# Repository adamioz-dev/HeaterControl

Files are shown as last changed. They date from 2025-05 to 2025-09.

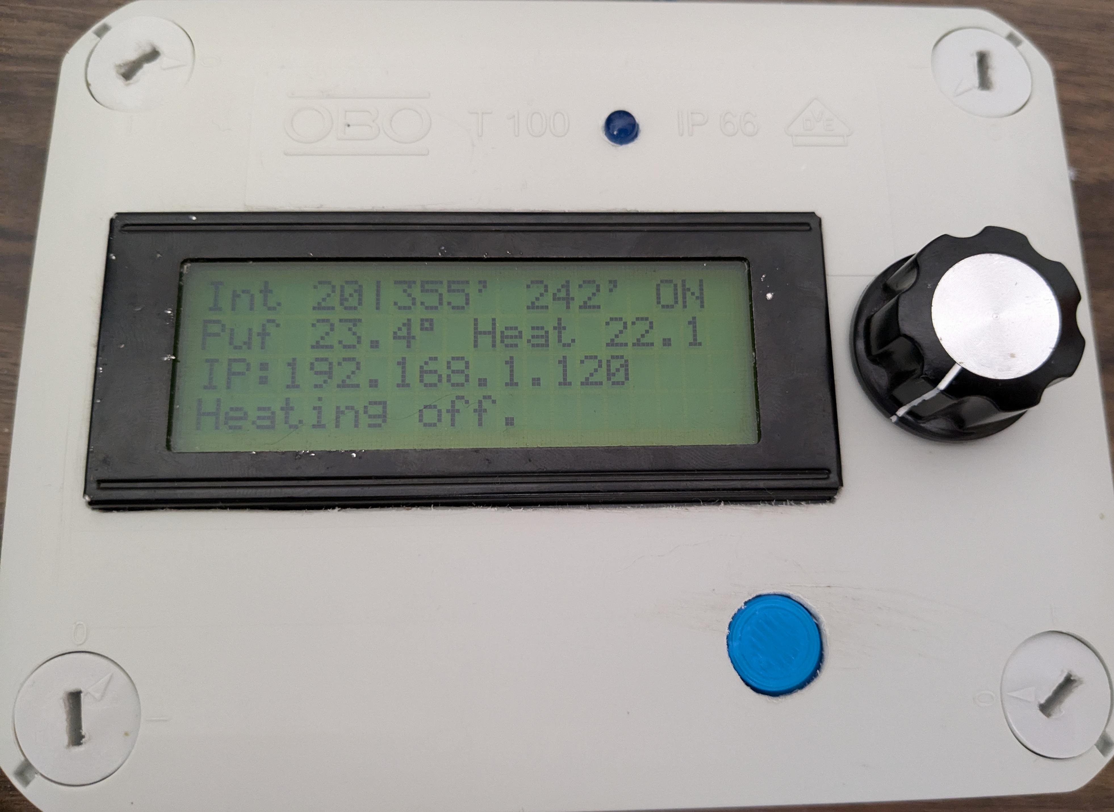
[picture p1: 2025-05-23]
resources/Assembly_front_in_electrical_box.jpg

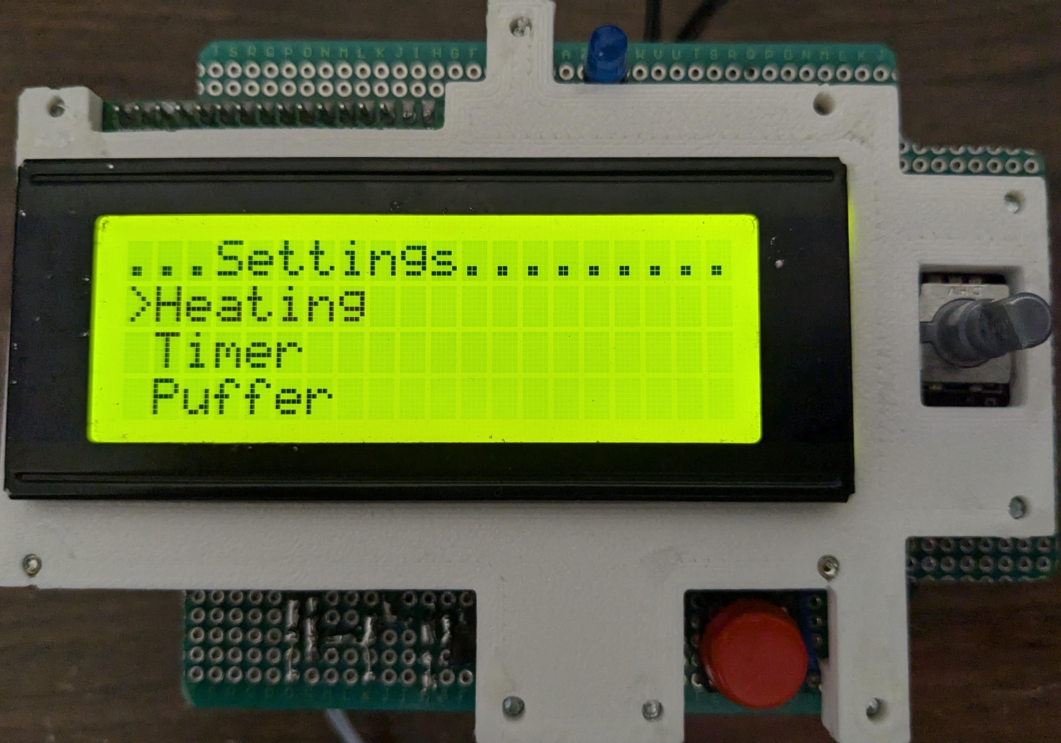
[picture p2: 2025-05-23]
resources/Assembly_front.jpg

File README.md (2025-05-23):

# HeaterControl
The repository contains the code for a heater control project based on the Arduino framework using the PlatformIO envirmoment using python scripts to perform automatic versioning. 

About the project: 
This is used for fire wood heaters which come with water rezervoirs (puffer) to store the heat generated and distribuite it when needed.
The hot water from the rezervoir is transfered to the building heater system to heat it up, this is achieved by controling the pump with a relay. 

Features as implemented in each controller:
1) The slave atmega328 controller (arduino uno) responsable for:
- inputs (lcd, encoder, button, (optional) external termostat on/off connection)
- relay control (for controlling the water pump to transfer heat from the puffer to the building)
- temperature measurements (heater water temperature and the puffer temperature - min/max can be set)
- over-temperature protection for the puffer.
- prevent enabling of pump when the puffer temperature is too low and heating is not possible.
- communicate the measurement/settings/states to the master controller on UART.
2) The master esp8266 controller (nodemcu)  responsable for:
- handle conection to the internet using WiFi
- hosting web pages for settings, control, data logging available on local network.
- conection with blynk (for smartphone access anywhere, blynk OTA) (optional)
- flashing over the air (OTA on same network)
- flashing of slave controller when update is received.
- receive room temperature measurements over direct HTTP or MQTT connection (MQTT broker required).
- MQTT publish measurements and subscribe to control values and room temperature (MQTT broker required).
- estimate home room temperature if it was not received for some time (for up to 2h)

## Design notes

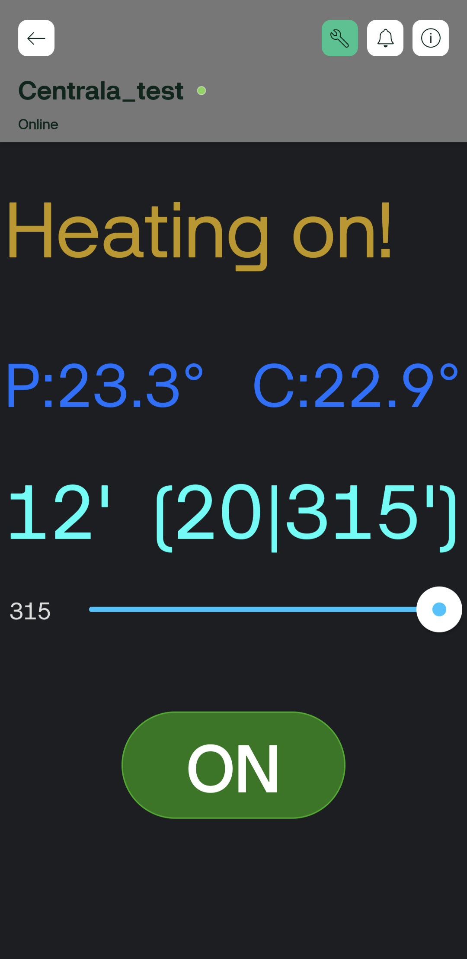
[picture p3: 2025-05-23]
resources/blynk_app_example.png

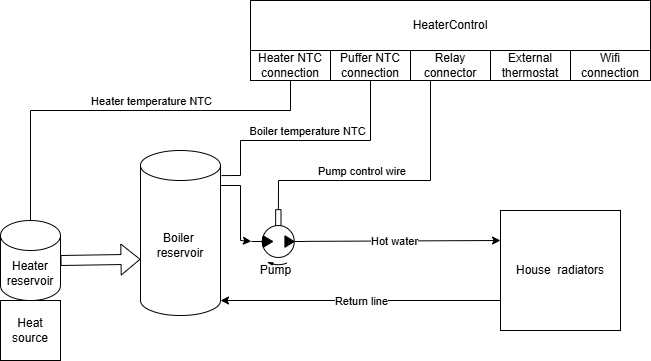
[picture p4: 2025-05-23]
resources/InstalationDiagram.png

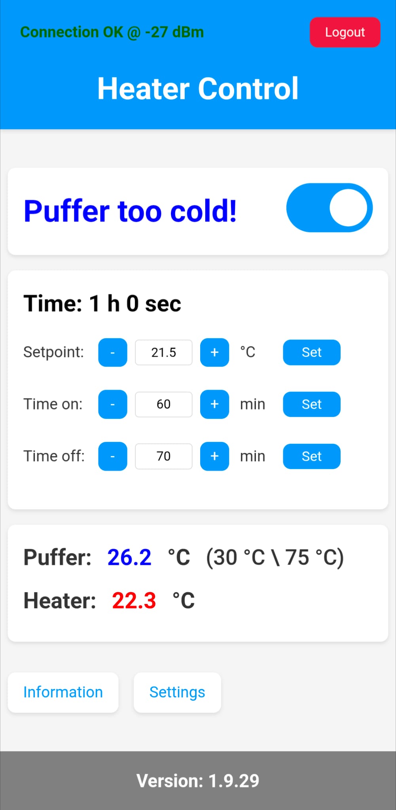
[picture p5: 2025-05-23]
resources/WebPage.jpg

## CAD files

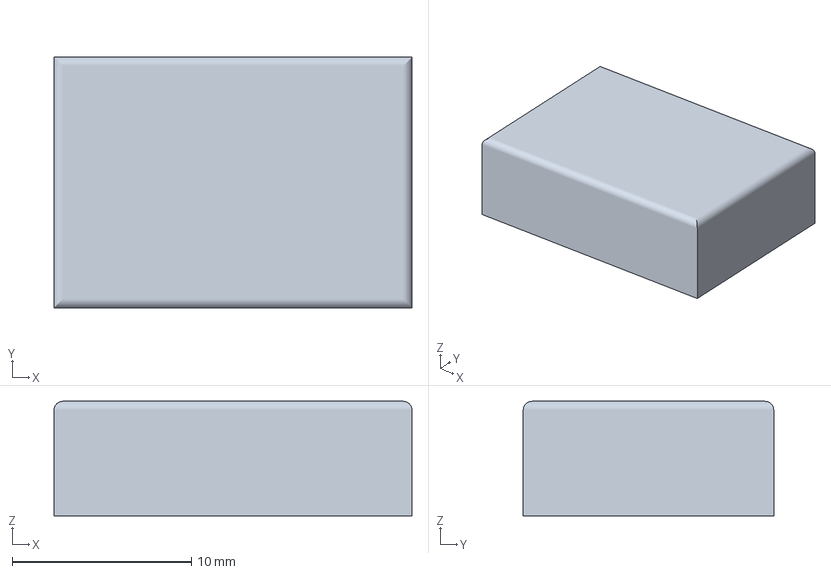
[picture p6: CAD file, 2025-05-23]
resources/3d_models/encoder_stand.3MF
20.0 x 14.0 x 6.40 mm

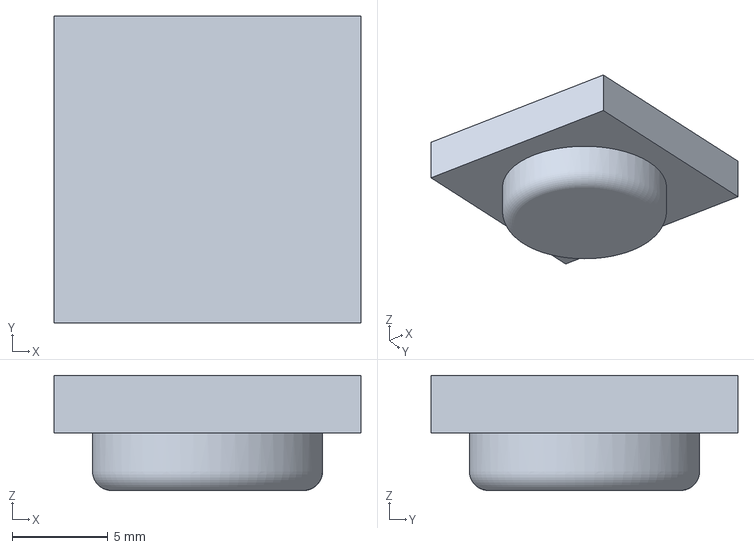
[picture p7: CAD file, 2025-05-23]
resources/3d_models/button_riser.3MF
16.0 x 16.0 x 6.00 mm

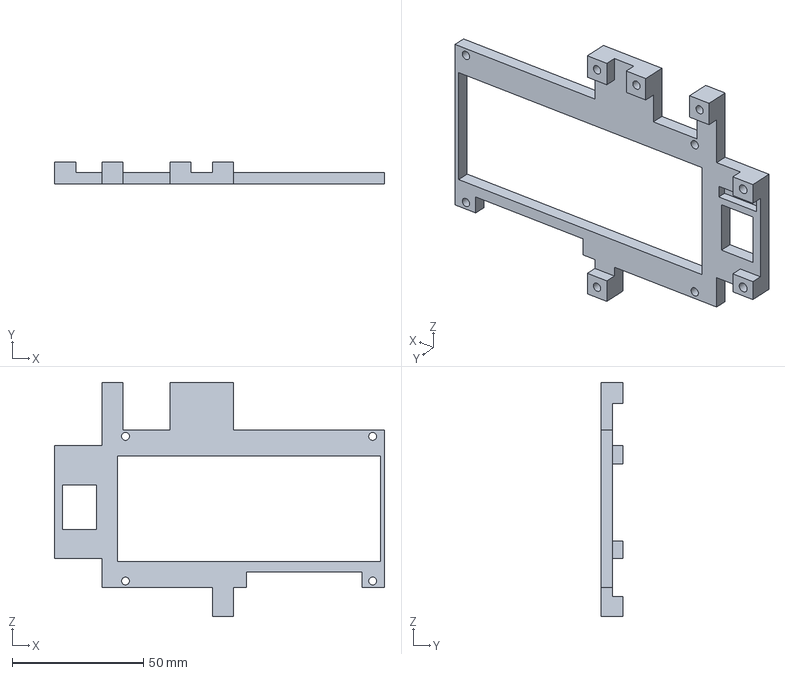
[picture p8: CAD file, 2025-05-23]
resources/3d_models/PCB_holder_frame.3MF
125.5 x 8.50 x 89.0 mm

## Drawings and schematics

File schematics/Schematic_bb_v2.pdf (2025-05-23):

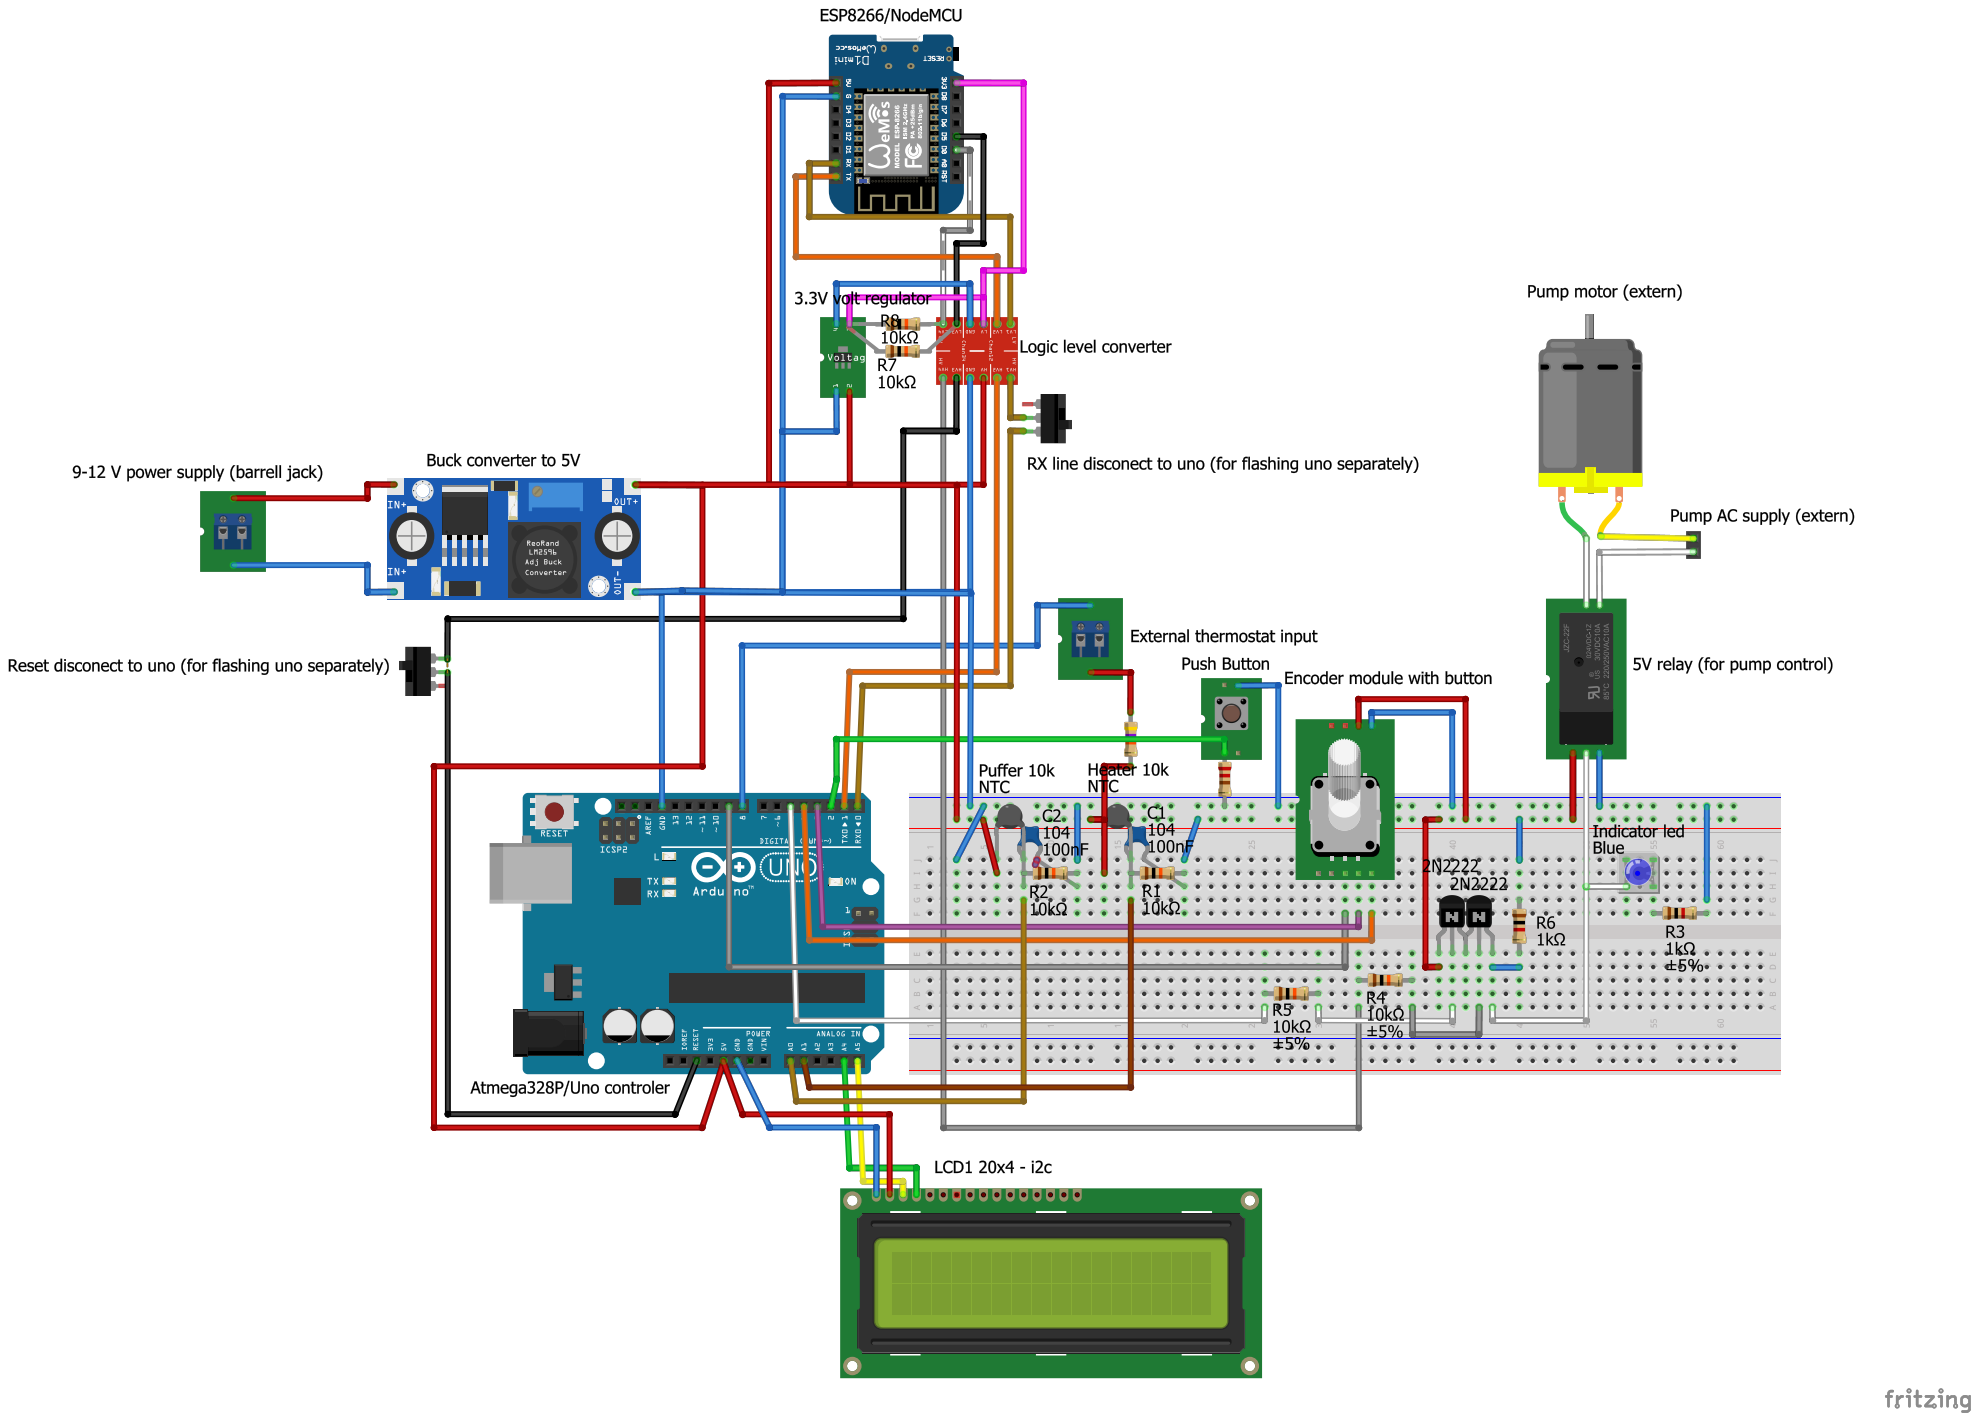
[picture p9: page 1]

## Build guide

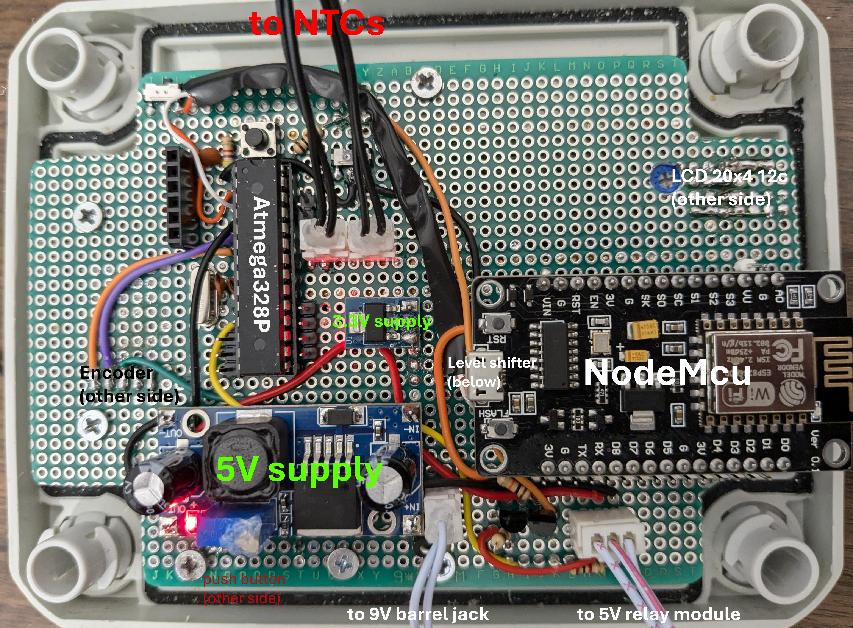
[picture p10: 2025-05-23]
resources/Assembly_back.jpg

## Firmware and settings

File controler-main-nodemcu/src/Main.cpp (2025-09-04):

// *********************************************************************
// INCLUDES
// *********************************************************************
#include "Main.h"
#include <EEPROM.h>
#include "ProjVersion.h"
#include "MQTT.h"
// *********************************************************************
// DEFINES
// *********************************************************************

// *********************************************************************
// DATATYPES
// *********************************************************************
struct {
  uint32_t flash_request;
  uint32_t flash_attempts;
  uint32_t reserved[3];
} rtcData;

typedef struct {
  // heating parameters
  float heating_puffer_coef =       200;
  float heating_result_multiplier = 2;
  // cooling params
  float cooling_room_coef =         75;
  float cooling_result_multiplier = 12;
}tempAproxCalib_t;

// *********************************************************************
// GLOBAL VARIABLES
// *********************************************************************
// temp aproximation calib data
tempAproxCalib_t calibData;

//room temperature timeout counter
uint16_t roomTempUpdateTimeout_cnt = 0u;

// intervals for scheduler
unsigned long g_fast_task_interval_cnt =    0; 
unsigned long g_mid_task_interval_cnt =     0; 
unsigned long g_slow_task_interval_cnt =    0; 
unsigned long g_minute_task_interval_cnt =  0; 

// comunicated values 
ComTransmitData comTransmitData;

// uptime counter
unsigned long g_esp_uptime = 0; 

// data received marker
bool data_received = false;

// marker for communication error, starup flag set as error present
bool communication_error = true;

//webserver request flags 
bool uno_flash_req_flag = false;
bool uno_reset_req_flag = false;
bool esp_reset_req_flag = false;

/* Init value */
flash_resp_t flash_status = FLASH_INFO_NOT_AVAIL;

/* extern stuff */
extern bool AP_mode_active; 

// *********************************************************************
// FUNCTION DECLARATIONS 
// *********************************************************************
void versionCheck();
void mqttCallback(char* topic, byte* payload, unsigned int length);

// *********************************************************************
// FUNCTIONS
// *********************************************************************

void reset_uno(){
  // reset the uno controler
  DEBUG_PRINT_LN("Reset the AVR UNO");
  digitalWrite(UNO_RESET_PIN, LOW); // when pulled low, the uno will reset
  delay(100);
  digitalWrite(UNO_RESET_PIN, HIGH); // return to normal
  delay(50);
}

void check_uno(){
  // must be called slower than the uni will report the time
  uint32_t local_uno_uptime = comTransmitData.get_unoUptime();
  static uint32_t local_uno_uptime_prev = 0;
  static uint8_t local_reset_timeou_cnt = 0;

  static uint8_t local_reset_attepmts_cnt = 0;
  // uptime did not change
  if (local_uno_uptime_prev == local_uno_uptime)
  {
    // reset after the sepecified periods (in 10s of seconds)
    if ((local_reset_timeou_cnt >= UNO_RESET_WAIT) && (local_reset_attepmts_cnt <= UNO_RESET_TRIES))
    {
      // timeout of communication with uno, watchdog of uno failed to reset, communication not restored
      DEBUG_PRINT_LN("Resetting uno!");
      reset_uno();
      // clear reset counter
      local_reset_timeou_cnt = 0;
      // increment reset attempts
      local_reset_attepmts_cnt += 1;      
    }
    else if (local_reset_attepmts_cnt > UNO_RESET_TRIES)
    {
      DEBUG_PRINT_LN("Resettings failed, flash uno!");
      // attempt flashing
      flash_uno_req();
      // clear max reset counter, uno will be re-flashed 
      local_reset_attepmts_cnt = 0;
    }
    else
    {
      /* counter not finished yet */
      // uno is not sending data, increase reset counter
      local_reset_timeou_cnt++;
    }

    /* update reported state with error message */
    communication_error = true;
    /* set com error */
    (void)comTransmitData.set_Feedback((uint8_t)UNO_COM_ERR);
  }
  else
  {
    // connection seems ok, clear reset counter as well
    local_reset_attepmts_cnt = 0;
    // comunication restored, clear counter
    local_reset_timeou_cnt = 0;
    /* update reported state with error message */
    communication_error = false;
    /* Com error wil be cleared with the new feedback received */
  }

  // save previous uptime
  local_uno_uptime_prev = local_uno_uptime;
}

String processFeedbackCode(){
  uint8_t local_feedback_code = comTransmitData.get_Feedback();
  String returnText = "";
  /* normal operation */
  switch(local_feedback_code)
  {
    case HEATING_OFF: 
      {
      returnText = F("Heating off."); //heat off
      }
      break;
    case HEATING_ON:
      {
      returnText = F("Heating on!"); //heat on
      }
      break;
    case PUFFER_TEMP_LOW:
      {
      returnText = F("Puffer too cold!"); //low temp
      }
      break;
    case PUFFER_TEMP_OVERHEAT:
      {
      returnText = F("Puffer too hot!"); //high temp
      }
      break;
    case UNO_COM_ERR:
      {
      returnText = F("Control error!"); // uno not responding
      }
      break;
    default:
      {
      returnText = F("Unknown!");
      }
      break;  
  }
  
  return returnText;
}

void receiveValue(uint8_t id, uint32_t value){
  // set the value of the received variable
  //DEBUG_PRINT("Received:");
  //DEBUG_PRINT(id);
  //DEBUG_PRINT("=");
  //DEBUG_PRINT_LN(value);
  switch (id)
  {
    case _ID_HEATER_MODE:
    {
      //DEBUG_PRINT("UNO: Mode request ");
      //DEBUG_PRINT_LN(value);
      (void)comTransmitData.setHeating_mode((uint8_t)value);
      break;
    }
    case _ID_TIMER_ON_TIME:
    {
      //DEBUG_PRINT("UNO: Timer on ");
      //DEBUG_PRINT_LN(value);
      (void)comTransmitData.setHeatingTimer_ontime((uint16_t)value);
      break;
    }
    case _ID_TIMER_OFF_TIME:
    {
      //DEBUG_PRINT("UNO: Timer off ");
      //DEBUG_PRINT_LN(value);
      (void)comTransmitData.setHeatingTimer_offtime((uint16_t)value);
      break;
    }
    case _ID_AMBIENT_TARGET_TEMP:
    {
      //DEBUG_PRINT("Target room temp update from UNO: ");
      //DEBUG_PRINT_LN(value);
      (void)comTransmitData.setHeatingTermostat_target_ambient((uint16_t)value);
      break;
    }
    case _ID_AMBIENT_HYSTERESIS:
    {
      (void)comTransmitData.setHeatingTermostat_hysteresis((uint8_t)value);
      break;
    }
    case _ID_PUFFER_MIN_TEMP:
    {
      (void)comTransmitData.setPuffer_minTemp((uint8_t)value);
      break;
    }
    case _ID_PUFFER_MAX_TEMP:
    {
      (void)comTransmitData.setPuffer_maxTemp((uint8_t)value);
      break;
    }
    case _ID_PUFFER_HYSTERESIS:
    {
      (void)comTransmitData.setPuffer_hysteresis((uint8_t)value);
      break;
    }
    /// runtime values
    case _ID_HEATER_TRIGGER_REQUEST:
    {
      // here is received, don't set the send flag
      (void)comTransmitData.setHeating_TriggerRequest((uint8_t)value);
      break;
    }
    case _ID_TIMER_REMAINING_SEC:
    {
      // receive only, except in case of uno reset-restore
      (void)comTransmitData.setHeatingTimer_TimeRemaining_sec((uint16_t)value);
      break;
    }
    case _ID_AMBIENT_ACTUAL_ROOM_TEMP:  
    {
      // room temperature
      (void)comTransmitData.setHeatingTermostat_AmbientTemp((uint16_t)value, false);
      break;
    }
    case _ID_AMBIENT_ACTUAL_ROOM_TEMP_VALID:
    {
      // room temp valid received
      (void)comTransmitData.setHeatingTermostat_AmbientTemp_Valid((uint8_t)value, false);
      break;
    }
    case _ID_THERMOSTAT_STATE:
    {
      //DEBUG_PRINT("UNO: External thermostat state ");
      //DEBUG_PRINT_LN(value);
      // termostat external pin state
      (void)comTransmitData.setHeatingExternalTermostat_State((uint8_t)value);
      break;
    }
    case _ID_PUFFER_TEMP:
    {
      // receive only
      (void)comTransmitData.setPuffer_Temp((uint16_t)value);
      break;
    }
    case _ID_HEATER_TEMP:
    {
      // receive only
      (void)comTransmitData.setBoiler_Temp((uint16_t)value);
      break;
    }

    case _ID_FEEDBACK_CODE:
    {
      // receive only
      (void)comTransmitData.set_Feedback((uint8_t)value);
      break;
    }
    case _ID_IP_ADDRESS:
    {
      // send only
      break;
    }
    case _ID_UPTIME_UNO:
    {
      // receive only
      (void)comTransmitData.set_unoUptime((uint32_t)value);
      //DEBUG_PRINT("Uptime received:");
      //DEBUG_PRINT_LN(value);
      break;
    }
    case _ID_DATA_GROUP1:
    {
      // send only
      break;
    }
    case _ID_DATA_GROUP2:
    {
      // send only
      break;
    }
    case _ID_VERSION:
    {
      // Receive uno specific data
      version_data_t version_data_temp_store; // temp variable 
      version_data_t version_data_temp_recv; // temp variable 
      // get to temp variable
      version_data_temp_recv.all = (uint32_t)value;

      // get relevant data only, uno version
      version_data_temp_store.version_byte[1] = version_data_temp_recv.version_byte[1]; // uno version

      version_data_temp_store.version_byte[0] = (uint8_t)PROJECT_MAJOR; // keep original
      version_data_temp_store.version_byte[2] = (uint8_t)PROJECT_ESP;   // keep original
      version_data_temp_store.version_byte[3] = (uint8_t)flash_status;  // keep original
      // store received version
      (void)comTransmitData.set_version_all((uint32_t)version_data_temp_store.all, false);
      break;
    }
    case _ID_LAST:
    {
      // Check if the values are requested and the esp been already running and received data already
      if (((uint8_t)value == 1) && (g_esp_uptime > 60) && (data_received == true)) 
      {
        DEBUG_PRINT_LN("Data was requested. Sending last know data.");
        // data was requested from uno
        // send the confirmation that termostat data is received
        sendPacket(_ID_AMBIENT_ACTUAL_ROOM_TEMP, (uint16_t)(comTransmitData.getHeatingTermostat_AmbientTemp() * FLOAT_SCALING));
        sendPacket(_ID_AMBIENT_ACTUAL_ROOM_TEMP_VALID, (uint8_t)(comTransmitData.getHeatingTermostat_AmbientTemp_Valid()));
        // last known heater request
        sendPacket(_ID_HEATER_TRIGGER_REQUEST, (uint8_t)comTransmitData.getHeating_TriggerRequest()); 
        //timer
        sendPacket(_ID_HEATER_MODE, (uint8_t)comTransmitData.getHeating_mode());
        sendPacket(_ID_TIMER_ON_TIME, (uint16_t)comTransmitData.getHeatingTimer_ontime());
        sendPacket(_ID_TIMER_OFF_TIME, (uint16_t)comTransmitData.getHeatingTimer_offtime());
        sendPacket(_ID_TIMER_REMAINING_SEC, (uint16_t)comTransmitData.getHeatingTimer_TimeRemaining_sec());
        // termostat
        sendPacket(_ID_AMBIENT_TARGET_TEMP, (uint16_t)(comTransmitData.getHeatingTermostat_target_ambient() * FLOAT_SCALING));
        sendPacket(_ID_AMBIENT_HYSTERESIS, (uint8_t)(comTransmitData.getHeatingTermostat_hysteresis() * FLOAT_SCALING));
        // puffer
        sendPacket(_ID_PUFFER_MIN_TEMP,(uint8_t)comTransmitData.getPuffer_minTemp());
        sendPacket(_ID_PUFFER_MAX_TEMP, (uint8_t)comTransmitData.getPuffer_maxTemp());
        sendPacket(_ID_PUFFER_HYSTERESIS, (uint8_t)comTransmitData.getPuffer_hysteresis());
        // send version
        sendPacket(_ID_VERSION, (uint32_t)comTransmitData.get_version_all());
      }
    }
    default:
    {
      break;
    }
  }
  data_received = true;
}

void toogle_led(){
  static bool led_status = false;
  // blink led when alive 
  digitalWrite(LEDPIN, led_status); // turn on led 
  led_status = !led_status;
}

void receiveRoomTemp(float room_temperature)
{
  // float scaling applies for 19.5 send 195
  (void)comTransmitData.setHeatingTermostat_AmbientTemp((uint16_t)(room_temperature * FLOAT_SCALING), true);
  // set valid temp flag
  (void)comTransmitData.setHeatingTermostat_AmbientTemp_Valid((bool)true , true);
  /* reset timeout counter */
  roomTempUpdateTimeout_cnt = 0;
  //call the temp aprox fuction
  aproximateRoomTemp(); 
}

void receiveRoomTempBattery(float battery_volt)
{
  // float scaling applies for 2.8 send 28
  (void)comTransmitData.setHeatingTermostat_AmbientTempBattery((uint8_t)(battery_volt * FLOAT_SCALING));
}

uint16_t calculateTimeToIncreaseTemp(float local_puffer_temp, float local_room_temp)
{
  // calculate time in minutes required to increase temperature by 0.1 C
  uint16_t local_timeStep = (uint16_t)((1 / (local_puffer_temp - local_room_temp) * calibData.heating_puffer_coef) * calibData.heating_result_multiplier);

  DEBUG_PRINT("Calculated time step for increase: "); 
  DEBUG_PRINT_LN(local_timeStep);
  
  return local_timeStep;
}

uint16_t calculateTimeToDecreaseTemp(float local_room_temp)
{
  // calculate time in minutes required to decrease temperature by 0.1 C
  uint16_t local_timeStep =  (uint16_t)((1 / local_room_temp * calibData.cooling_room_coef) * calibData.cooling_result_multiplier);
  
  DEBUG_PRINT("Calculated time step for decrease: "); 
  DEBUG_PRINT_LN(local_timeStep);
  
  return local_timeStep;
}

/* aproximate room temp between measurement points (each min)*/
void aproximateRoomTemp()
{
  static uint16_t local_timeSinceLastTempUpdateByStep = 0;
  static bool local_heating_status_prev = true;
  static uint16_t local_calculatedTempStep = 0u;
  static float local_room_temperature_received = 0;
  static uint8_t local_send_counter = 0;
  static float local_room_temperature_aprox = 0;

  float local_room_temperature = 0;
  uint8_t local_feedback_code = HEATING_OFF;
  bool local_heating_status = false;
  bool local_temperature_data_valid = false;

  float local_puffer_temp = 0;

  local_puffer_temp = comTransmitData.getPuffer_Temp();
  local_room_temperature = comTransmitData.getHeatingTermostat_AmbientTemp();
  local_feedback_code =  (uint8_t)comTransmitData.get_Feedback();
  local_temperature_data_valid = comTransmitData.getHeatingTermostat_AmbientTemp_Valid();

  // check if data is valid
  if((local_temperature_data_valid == false) || (local_room_temperature == 0))
  {
    //DEBUG_PRINT("Room temp not valid -");
    //DEBUG_PRINT_LN(local_temperature_data_valid);
    //DEBUG_PRINT(" T: ");
    //DEBUG_PRINT_LN(local_room_temperature);
    // no valid temp, exit
    local_room_temperature_aprox = 0;
    return;
  }

  // identify what is the heating state
  if ((local_feedback_code == HEATING_OFF) || (local_feedback_code == PUFFER_TEMP_LOW))
  {
    // no heating
    local_heating_status = false;
  }
  else if ((local_feedback_code == HEATING_ON) || (local_feedback_code == PUFFER_TEMP_OVERHEAT))
  {
    // heating is on
    local_heating_status = true;
  }

  // Check if timeout is reached
  if (roomTempUpdateTimeout_cnt >= ROOM_TEMP_TIMEOUT)
  {
    DEBUG_PRINT_LN("Room temp timeout reached.");
    // mark room temp data as not valid and send to uno
    (void)comTransmitData.setHeatingTermostat_AmbientTemp_Valid((bool)false, true);
    // set 0 room temp for esp
    (void)comTransmitData.setHeatingTermostat_AmbientTemp((uint16_t)0, false); 
    // clear 
    local_timeSinceLastTempUpdateByStep = 0;
    local_calculatedTempStep = 0;
    // switch to timer mode
    (void)comTransmitData.setHeating_mode(TIMER_MODE, true);
  }
  else  // normal operation, room temp is not timeout
  {
    if (roomTempUpdateTimeout_cnt == 0)
    {
      /// TODO: compare with actual time and adjust the calibData for increase or decrease accordingly

      DEBUG_PRINT("Room temp was updated: ");
      DEBUG_PRINT_LN(local_room_temperature);

      // just received the temperature, clear counter
      local_timeSinceLastTempUpdateByStep = 0;
      if (local_heating_status == true) 
      {
        // calculate time needed increase temperature by 0.1 C while heating
        local_calculatedTempStep = calculateTimeToIncreaseTemp(local_puffer_temp, local_room_temperature);
      }
      else
      {
        // calculate time needed decrease temperature by 0.1 C while cooling
        local_calculatedTempStep = calculateTimeToDecreaseTemp(local_room_temperature);
      }
      // save received temperature
      local_room_temperature_received = local_room_temperature;
      // set calulated aprox room temp to the received value
      local_room_temperature_aprox = local_room_temperature;
    }

    // increment counter for time spent in the last state
    local_timeSinceLastTempUpdateByStep++;
    // increment timeout counter 
    roomTempUpdateTimeout_cnt++;

    // time passed, increase aproximate temp
    if (local_timeSinceLastTempUpdateByStep >= local_calculatedTempStep)
    {
      DEBUG_PRINT_LN("Time step reached.");
      DEBUG_PRINT("Current aprox temp: ");
      DEBUG_PRINT_LN(local_room_temperature_aprox);
      // calculate aproximate room temp while heating
      if (local_heating_status == true) 
      {
        // calculate next time needed increase temperature by 0.1 C
        local_calculatedTempStep = calculateTimeToIncreaseTemp(local_puffer_temp, local_room_temperature_aprox);
        // clear counter
        local_timeSinceLastTempUpdateByStep = 0;
        
        // limit the max increase to 3 C above received value
        if (local_room_temperature_aprox <= local_room_temperature_received + 3)
        {
          // aproximate room temp increase
          local_room_temperature_aprox = local_room_temperature_aprox + 0.1; // increase by 0.1 C
          DEBUG_PRINT("Increase aproximate temp.:");
          DEBUG_PRINT_LN(local_room_temperature_aprox);
        }
      }
      else // no heating
      {
        // calculate next time needed decrease temperature by 0.1 C
        local_calculatedTempStep = calculateTimeToDecreaseTemp(local_room_temperature_aprox);
        // clear counter
        local_timeSinceLastTempUpdateByStep = 0;

        // limit the max decrease to 3 C above received value
        if (local_room_temperature_aprox >= local_room_temperature_received - 3)
        {
          // aproximate room temp decrease
          local_room_temperature_aprox = local_room_temperature_aprox - 0.1; // decrease by 0.1 C
          DEBUG_PRINT("Decrease aproximate temp.:");
          DEBUG_PRINT_LN(local_room_temperature_aprox);
        }
      }
      // send updated value
      DEBUG_PRINT_LN("Send new aproximation.");
      (void)comTransmitData.setHeatingTermostat_AmbientTemp((uint16_t)(local_room_temperature_aprox * FLOAT_SCALING), true); 
      // reset counter
      local_send_counter = 0;
    }
    
    // feedback code changed, heating state changed
    if (local_heating_status != local_heating_status_prev)
    {
      DEBUG_PRINT_LN("Heating state changed");
      // clear counter
       local_timeSinceLastTempUpdateByStep = 0u;
      // update the prev heating status
      local_heating_status_prev = local_heating_status;

      if (local_heating_status == true) 
      {
        // calculate time needed increase temperature by 0.1 C while heating
        local_calculatedTempStep = calculateTimeToIncreaseTemp(local_puffer_temp, local_room_temperature_aprox);
      }
      else
      {
        // calculate time needed decrease temperature by 0.1 C while cooling
        local_calculatedTempStep = calculateTimeToDecreaseTemp(local_room_temperature_aprox);
      }
    }

    if (local_send_counter > 10){ // every 10 min
      DEBUG_PRINT("Send periodic the temperature: ");
      DEBUG_PRINT_LN(local_room_temperature_aprox);
      // send value periodically
      (void)comTransmitData.setHeatingTermostat_AmbientTemp((uint16_t)(local_room_temperature_aprox * FLOAT_SCALING), true); 
      // reset counter
      local_send_counter = 0;
    }
    // increase counter
    local_send_counter++;
  }
}

void handleWebServerRequests(void)
{
  if (uno_flash_req_flag == true)
  {
    /* clear flag */
    uno_flash_req_flag = false;
    // perform flash request
    flash_uno_req();
  }
  if (uno_reset_req_flag == true)
  {
    /* clear flag */
    uno_reset_req_flag = false;
    // perform reset 
    reset_uno();
  }
    if (esp_reset_req_flag == true)
  {
    /* clear flag */
    esp_reset_req_flag = false;
    // perform reset 
    ESP.restart();
  }
}

// *************************************************
//                  Tasks                        
// *************************************************
void fast_task()
{
  //uptime
  g_esp_uptime = (unsigned long)(millis() / 1000);

  // ota loop
  loop_ota();
}

void middle_task()
{

  // blynk loop for application
  loop_blynk();
  // normal running toggle led slow
  toogle_led();
  /* request data groupt 1*/
  sendPacket(_ID_DATA_GROUP1, (uint8_t)1); 

  /* process flags set by web interface */
  handleWebServerRequests();
}

void slow_task()
{
  // request group 2 
  sendPacket(_ID_DATA_GROUP2, (uint8_t)1); 

  // check for connection to the internet
  connectionCheck();
  // check if uno is alive
  check_uno();
  // check if version updated and update firmware
  versionCheck();
  // publish data to MQTT
  publishMqtt();
}

void minute_task()
{
  // webserver data 
  loop_webserver();
  // calculate the aproximate room temp (from last known)
  aproximateRoomTemp();


  /* TODO: Implement heating/fire detection? */
}

// *************************************************
//                  Scheduler                    
// *************************************************
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
void loop() {
  loop_mqtt();
  
  // scheduler
  scheduler(); //call scheduler

  //always
  loop_sw_uart();
}

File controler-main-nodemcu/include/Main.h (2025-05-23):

#ifndef MAIN_H
#define MAIN_H

#define WEBSERIAL_MSG
//#define DEBUG_SERIAL_HW

// debug messages
#if defined(DEBUG_SERIAL_HW)
/* debug second uart */
#define DEBUG_SERIAL Serial1

// Comment this out to disable prints and save space 
#define DEBUG_PRINT(x) DEBUG_SERIAL.print(x)
#define DEBUG_PRINT_TYPE(x,y) DEBUG_SERIAL.print(x,y)
#define DEBUG_PRINT_LN(x) DEBUG_SERIAL.println(x)
#define DEBUG_PRINT_TYPE_LN(x,y) DEBUG_SERIAL.println(x,y)
#elif defined(WEBSERIAL_MSG)
#include <WebSerial.h>
/* debug second web */
#define DEBUG_SERIAL WebSerial
#define DEBUG_PRINT(x) DEBUG_SERIAL.print(x)
#define DEBUG_PRINT_TYPE(x,y) DEBUG_SERIAL.print(x,y)
#define DEBUG_PRINT_LN(x) DEBUG_SERIAL.println(x)
#define DEBUG_PRINT_TYPE_LN(x,y) DEBUG_SERIAL.println(x,y)
#else
// no serial messages
#define DEBUG_PRINT(x)
#define DEBUG_PRINT_TYPE(x,y) 
#define DEBUG_PRINT_LN(x)
#define DEBUG_PRINT_TYPE_LN(x,y)
#endif

/* HW serial used to communicate with avr board */
#define COMMUNICATION_SERIAL Serial

// *********************************************************************
// INCLUDES
// *********************************************************************
#include <Arduino.h>
#include "common.h"
#include "UARTHandler.h"
#include "OTAHandler.h"
#include "WebServerHandler.h"
#include "BlynkHandler.h"
#include "AVRFlasher.h"
// *********************************************************************
// DEFINES
// *********************************************************************
// PINS
#if defined(DEBUG_SERIAL_HW)
// the LED_BUILTIN is used as HW tx serial for debug 
#define LEDPIN      5 //LED_BUILTIN is used for uart1 "serial1" tx
#else
// builtin can be used as led pin
#define LEDPIN      LED_BUILTIN
#endif

#define RELAY_ENABLE_PIN    0         // D3 conected to and gate on the relay inputs

// reset
#define UNO_RESET_PIN       14        // D5 conected to the reset pin of uno -> to target AVR RESET/DTR/GRN pin
#define UNO_RESET_WAIT      3         // in 10x seconds (is in slow task (3 = ~30sec) ) // should be bigger than the startup time of uno + margin   
#define UNO_RESET_TRIES     3         // The number of reset attempts before trying to re-flash   

// scheduler interval
#define FAST_TASK_PERIOD    100u 
#define MID_TASK_PERIOD     1000u  // 1 second
#define SLOW_TASK_PERIOD    10000u // 10 second
#define MINUTE_TASK_PERIOD  60000u // 1 minute

// room temp aproximation timeout
#define ROOM_TEMP_TIMEOUT    120  // max time to aproximate room temperature

#define SIZE_OF_VERSION  3u
// *********************************************************************
// DATATYPES
// *********************************************************************
// version info to be sent to uno
union version_data_t {
  uint8_t version_byte[4];
  uint32_t all;
};
// *********************************************************************
// GLOBAL VARIABLES
// *********************************************************************
// comunicated values 
extern ComTransmitData comTransmitData;

// uptime counter
extern unsigned long g_esp_uptime;

// marker for communication error
extern bool communication_error;

//webserver request flags 
extern bool uno_flash_req_flag;
extern bool uno_reset_req_flag;
extern bool esp_reset_req_flag;

// *********************************************************************
// FUNCTIONS
// *********************************************************************
void reset_uno();
void check_uno();
String processFeedbackCode();
void receiveValue(uint8_t id, uint32_t value);
void toogle_led();
void receiveRoomTemp(float room_temperature);
void receiveRoomTempBattery(float battery_volt);
uint16_t calculateTimeToIncreaseTemp(float local_puffer_temp, float local_room_temp);
uint16_t calculateTimeToDecreaseTemp(float local_room_temp);
/* aproximate room temp between measurement points (each min)*/
void aproximateRoomTemp();
void handleWebServerRequests(void);
void flash_uno_req(void);
void checkRTCData();
// *************************************************
//                  Tasks                        
// *************************************************
void fast_task();
void middle_task();
void slow_task();
void minute_task();
// *************************************************
//                  Scheduler                    
// *************************************************
void scheduler();
// *********************************************************************
// SETUP
// *********************************************************************
void setup();
// *********************************************************************
// LOOP
// *********************************************************************
void loop();

#endif // MAIN_H

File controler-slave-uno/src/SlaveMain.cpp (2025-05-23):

// *********************************************************************
// INCLUDES
// *********************************************************************
#include "LCDHandler.h" 
#include "UARTHandler.h"
#include "ControlVersion.h"
#include "MeasurementHandler.h"
#include "CommonData.h"

// *********************************************************************
// DEFINES
// *********************************************************************

// scheduler interval
#define FAST_TASK_PERIOD    100u  
#define MID_TASK_PERIOD     1000u  // 1 second
#define SLOW_TASK_PERIOD    10000u // 10 second

// timeout for losing communication with esp
#define communication_esp_timeout    60000 // 1 min

// timeout for switching to timer mode in room temp is timeout
#define roomTemp_update_time_timeout    1200000 // 20 min 

// temperature hysteresis for puffer
#define temperatureHysteresis 	2 	// puffer hysteresis (+/- x C) 


// *********************************************************************
// DATATYPES
// *********************************************************************

// *********************************************************************
// GLOBAL VARIABLES
// *********************************************************************

// actual room temp
uint16_t roomTemperature = SNA; // FLOAT_SCALING  // start with big value so heating does not start after startup
bool roomTemperature_data_valid = true;
unsigned long roomTemperature_update_time = 0;  // time since data was received

//timer mode switch flag
bool timerModeON_selected = true;
//timer heating period
int16_t remainingTimeInMode_sec = 0;  // variable to store calculated remaining time in current mode
int16_t remainingTimeInMode_min = 0;  // variable to store calculated remaining time minutes

uint16_t heatingTimePassed = 0u; //init
uint16_t restoredTimerValue = 0u;

// requested pump state
bool pumpState_request;
// the requested state of the pump from the timer
bool timer_pumpState_req;

// Scheduler variables
// intervals for scheduler
unsigned long g_fast_task_interval_cnt =    0; 
unsigned long g_mid_task_interval_cnt =     0; 
unsigned long g_slow_task_interval_cnt =    0; 

// external termostat pin state
bool thermostat_pin_state = LOW;

// feedback code for the pump state
int feedbackCode = PUFFER_TEMP_LOW;

// *********************************************************************
// DECLARATIONS
// *********************************************************************
void request_heating_state_change(int input_value);
void toogle_led();
int calculateRequiredTime();
void heatingStateHandler();
void set_room_temperature(uint16_t input_value);
void temperatureInputChecker();
bool heatingTemperatureStateHandler();
bool heatingThermostatStateHandler();
bool heatingTimerStateHandler();
void heatingPumpHandler();
void communicationTimoCheck();
void receiveValue(uint8_t id, uint32_t value);
void restoreRemainingTime();
void sendMsg_group1();
void sendMsg_group2();
int getFeedbackCode(void);

void fast_task();
void middle_task();
void slow_task();
void scheduler();

void setup ();
void loop ();
// *********************************************************************
// FUNCTIONS
// *********************************************************************
void request_heating_state_change(int input_value) {
  bool local_heater_state =     (bool)GET_SETTING_HEATER_STATE();
  uint8_t local_heater_mode = (uint8_t)GET_SETTING_HEATER_MODE();
  // if toggle of value requested
  if (input_value == TOOGLE_MODE) 
  {
    local_heater_state = !local_heater_state;
    SET_SETTING_HEATER_STATE((bool)local_heater_state);
  } 
  // if accepted values
  else if ((input_value == HEATER_OFF) || (input_value == HEATER_ON))
  {
    SET_SETTING_HEATER_STATE((bool)input_value);
  }

  if ((HEATER_ON == local_heater_state) && ((local_heater_mode == TIMER_MODE) || (local_heater_mode == TEMPERATURE_MODE)))
  {
    timerModeON_selected = true;
  }

  sendPacket(_ID_HEATER_TRIGGER_REQUEST, (uint8_t)local_heater_state); 
}

void toogle_led(){
  static bool led_status = false;
  // blink led when alive 
  digitalWrite(LEDPIN, led_status); // turn on led 
  led_status = !led_status;
}

// calculate and update the required on or off time
int calculateRequiredTime(){
  int local_heater_timer_ontime = GET_SETTING_TIME_ON();
  int local_heater_timer_offtime = GET_SETTING_TIME_OFF();
  if (timer_pumpState_req == HIGH)
  {  
    //Calculate next "on time"
    return (local_heater_timer_ontime * 60);
  }
  else
  { 
    //Calculate next "Off time"
    return (local_heater_timer_offtime * 60);
  }
}

void heatingStateHandler(){
  uint8_t local_heater_mode = (uint8_t)GET_SETTING_HEATER_MODE();
  switch (local_heater_mode)
  {
    case TIMER_MODE:
    {
      // call timer handler 
      pumpState_request = heatingTimerStateHandler();
      break;
    }
    case TEMPERATURE_MODE:
    {
      // check the input temoerature values
      temperatureInputChecker();
      // call temperature based handler 
      pumpState_request = heatingTemperatureStateHandler();
      break;
    }
    case THERMOSTAT_MODE:
    {
      // call external termostat handler 
      pumpState_request = heatingThermostatStateHandler();
      break;
    }
    default:
      // unknown state use timer
      SET_SETTING_HEATER_MODE(TIMER_MODE);
      break;
  }
}

// Room temperature transmited in termostat mode on web
void set_room_temperature(uint16_t input_value) {
  //limit inputs
  if (input_value >400){
    roomTemperature = 400;
  }else if (input_value < 10){
    roomTemperature = 10;
  }else{
    // get temperature in room
    roomTemperature = input_value;
  }
  // mark new room temperature received
  roomTemperature_update_time = millis();
  // mark receiving of data from termostat
  roomTemperature_data_valid = true;
}
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

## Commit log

2025-05-23 Add project files from local versioning
    [PCB_holder_frame.3MF, Schematic.fzz, button_riser.3MF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]
2025-09-04 Add configurable MQTT temperature receive topic (to be able to be used with ble gateways like TheengsGateway)
2025-09-04 Add enable/disable option for blynk from web settings page and wait times before checking blynk connection again (avoid remaining stuck in blynk library)
    [Main.cpp, Storage.h, WebServerHandler.cpp]
2025-12-04 Add reading of battery voltage through MQTT from sensor
2025-12-07 Change hist value from temp setpoint to battery voltage
